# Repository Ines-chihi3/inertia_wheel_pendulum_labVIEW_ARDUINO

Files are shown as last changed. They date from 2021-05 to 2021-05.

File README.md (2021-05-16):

# inertia_wheel_pendulum_labVIEW_ARDUINO

This is a project of designing and controlling the reaction wheel inverted pendulum based entirely on Arduino and labVIEW

https://user-images.githubusercontent.com/83761798/118369695-a4dad180-b5a4-11eb-9695-7480ea213706.mp4

I had the opportunity to work with 3 teammates : slim abid , sonia abbes and eya nagezi on a #LabVIEW project assigned by our professor in the National Institute of Applied Science and Technology in Tunisia.

The project is entitled "inertia wheel pendulum"  and is a well known benchmark in the field of controls . 
it consists of elaborating a system capable of stabilizing the pendulum on the inverted equilibrium point.
This principle is widely used in modern systems such as gymnastic robot .

The project involved  :

* making a mathematical model of the system
* hardware design with solidworks
* Developping a LabVIEW interface for data acquisition and control
* communication design using LINX package for interfacing between arduino and labVEIW
* comparing defferent type of controlor : LQR VS PID 
* Developping a #PID controller and tuning its parameters

This project, was a good opportunity for us to apply the theory we've been learning throughout this academic year , I want to thank my teammates for their support and perseverance .

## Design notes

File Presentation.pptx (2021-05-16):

## LABVIEW project

The inverted pendulum stabilized by a flywheel,
under-actuated non-linear system

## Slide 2

prepared by
Chihi Ines
Abbes Sonia
Abid Slim
Nagazi Eya
IIA4

## Motivation goals: GymnasRobots

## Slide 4

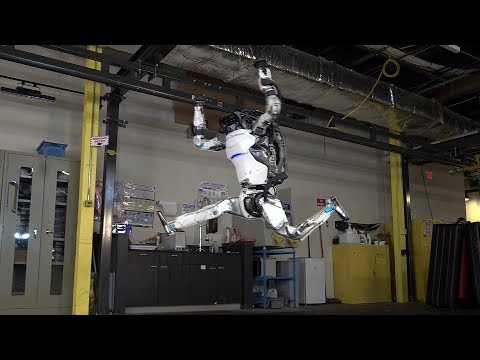
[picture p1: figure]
Atlas uses its whole body -- legs, arms, torso -- to perform a sequence of dynamic maneuvers that form a gymnastic routine. We created the maneuvers using new techniques that streamline the development process. First, an optimization algorithm transforms high-level descriptions of each maneuver in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

## The Benchmark

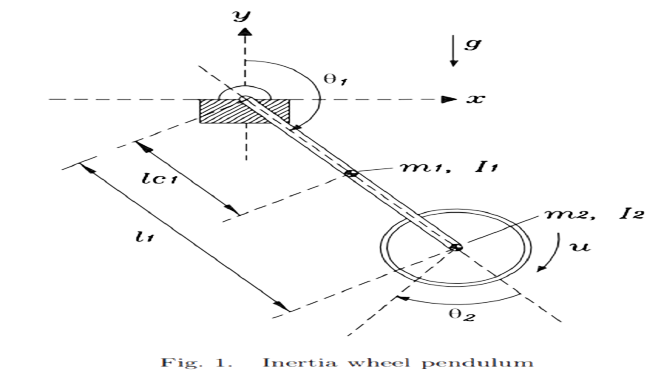
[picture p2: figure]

## Dynamic parameters

Notation | Description | Unit
L1 | Pendulum length | cm
Lc1 | the distance between the gravity center and the rotation axis | cm
m1 | Pendulum mass | Kg
m2 | Wheel mass | Kg
I1 | Pendulum Inertia | Kg.m²
I2 | Wheel Inertia | Kg.m²
g | gravity acceleration | m/s²

## Dynamic Variables

Notation | Description | Unit
θ1 | Pendulum angular position | rad
θ2 | Wheel angular position | rad
(θ1) ̇ | Pendulum angular velocity | rad/s
(θ2) ̇ | Wheel angular velocity | rad/s
(θ1) ̈ | Pendulum angular acceleration | rad/s²
(θ2) ̈ | Wheel angular acceleration | rad/s²
u | Motor torque | Nm

## Modelling hypotheses

Hypothesis 1: The masses of the pendulum and the inertia wheel are considered to be point masses located at their center gravity
Hypothesis 2: the friction mechanical phenomenal will be neglected
Hypothesis 3: The dynamics of the actuator motor associated with the wheel is not taken into account in the modelling of the system

## Theories

Lagrangian field theory:
Q =0 1 .u,
q= (θ1 θ2) T
L=K-V

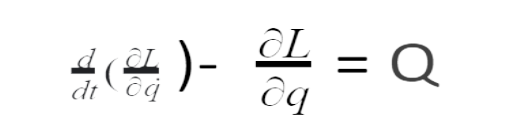
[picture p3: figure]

M=(m11,m12,m21,m22)
m11=m1.lc12+m2l12+I1+I2 m12=m21=m22

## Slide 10

## The dynamic model

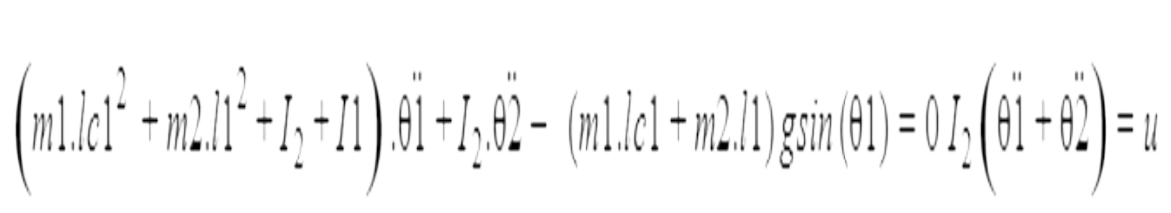
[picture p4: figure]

## Stabilisation

PID:
P:The proportional component depends only on the difference between the set point and the process variable.
I:The integral response will continually increase over time unless the error is zero
D:The derivative component causes the output to decrease if the process variable is increasing rapidly
LQR: Linear quadratic regulator is based on Riccati equations .Minimizing quadratic cost function with properly matched weights is the aim of the controller
target_voltage = a*p_angle + b*p_vel + c*m_vel
- a,b and c are weights
- pendulum angle - p_angle
- pendulum velocity - p_vel
- motor velocity - m_vel

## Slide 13

Model Conception

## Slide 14

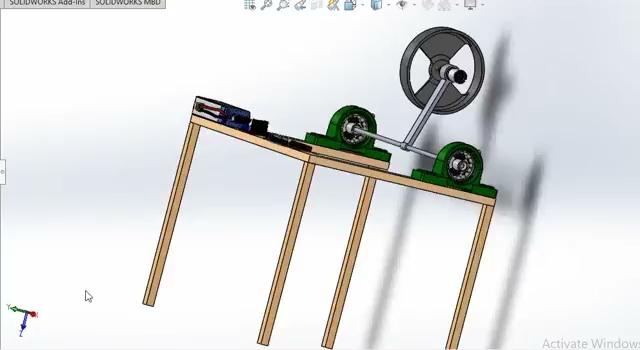
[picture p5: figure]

## Flowchart

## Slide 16

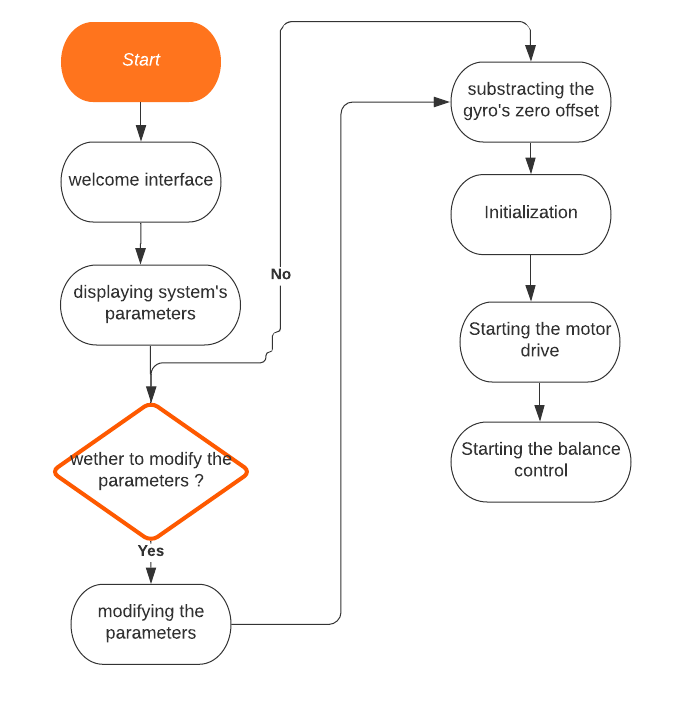
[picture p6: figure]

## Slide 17

Front Panel

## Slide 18

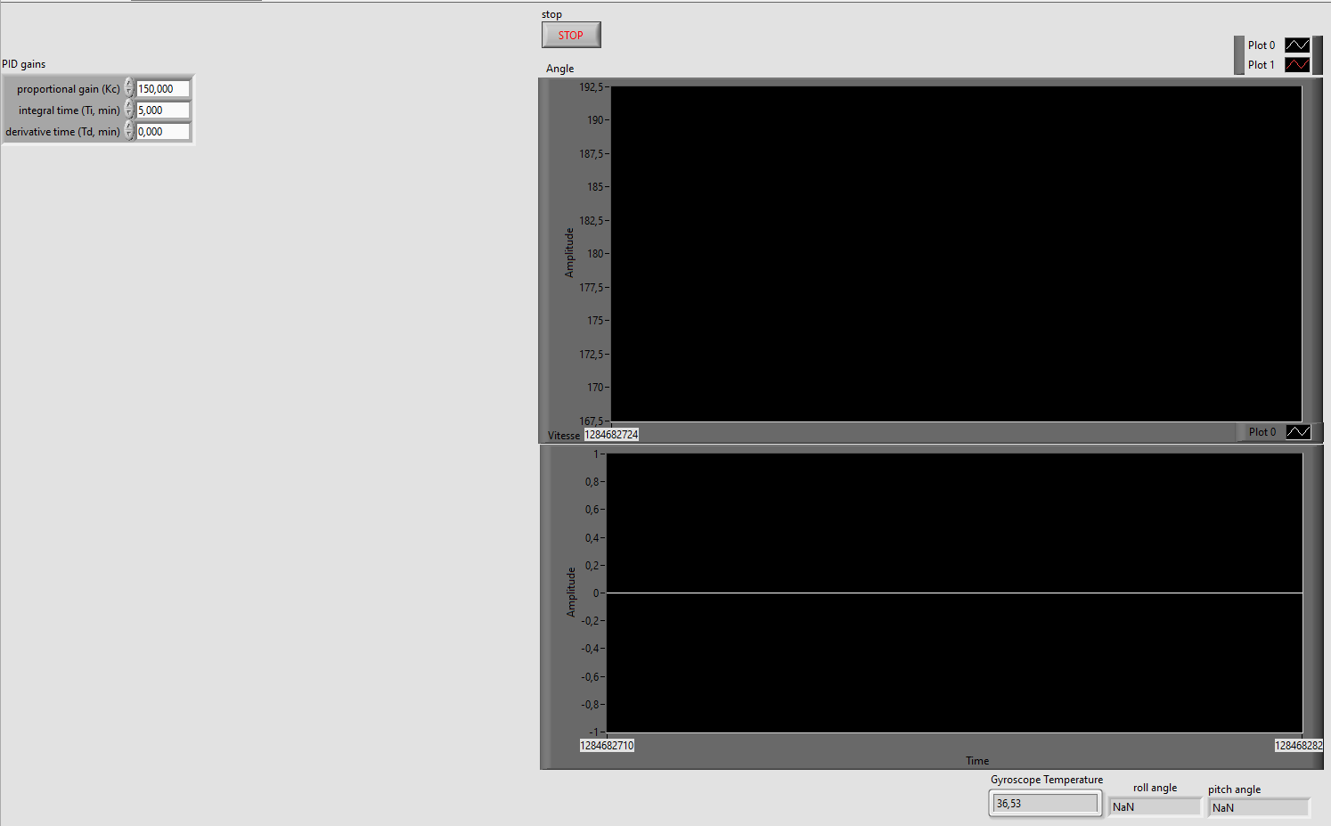
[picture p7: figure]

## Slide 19

Block diagram

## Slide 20

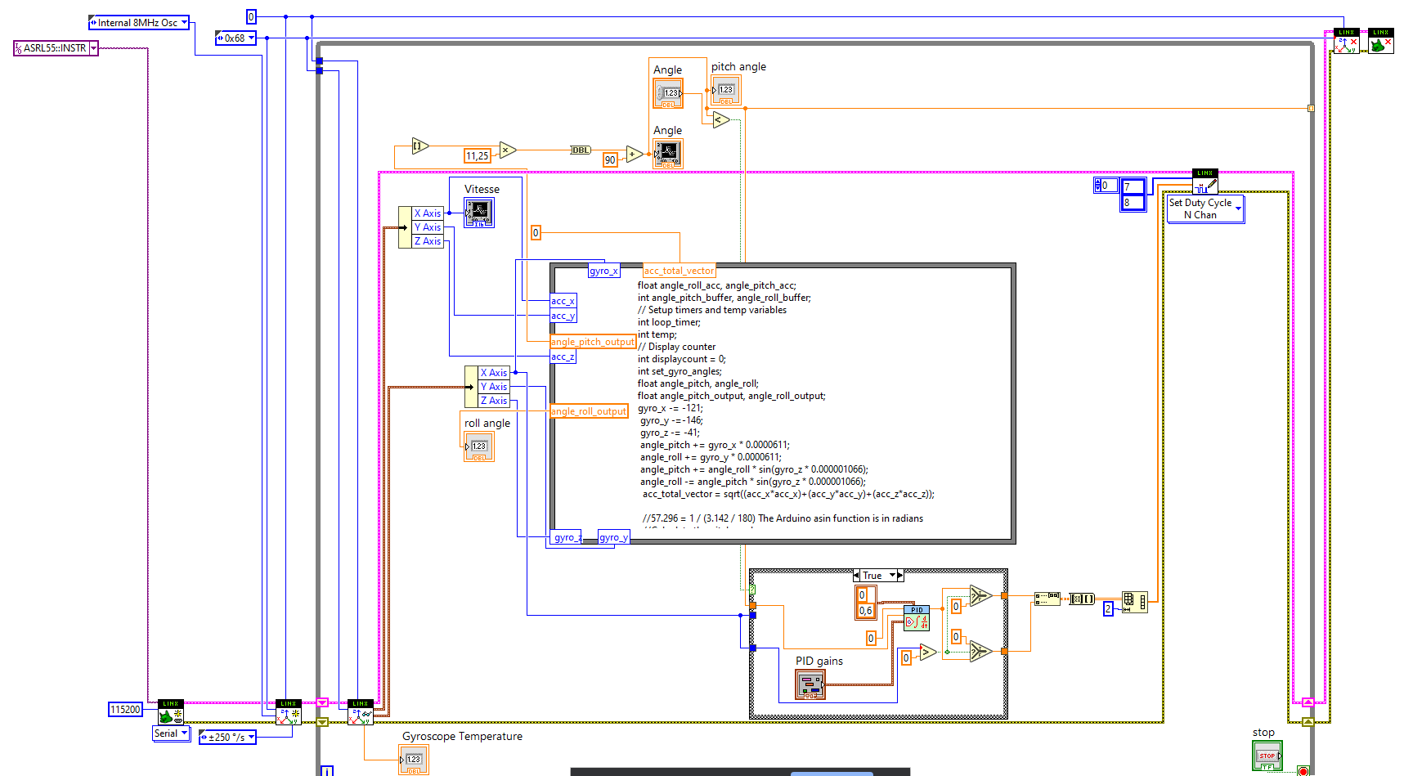
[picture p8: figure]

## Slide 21

Communication technology

Bluetooth: It is an unwired method that use bluetooth module to ensure the communication between the labview and the model
=> No real time results, Problem of latency
Serial: It is a wired method that uses a cable to communicate the software with the model

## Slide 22

Real time test

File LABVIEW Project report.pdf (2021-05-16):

LABVIEW Project report

The inverted pendulum stabilized by a flywheel, a under-actuated non-linear system

prepared by

Chihi Ines

Abbes Sonia

Abid Slim

Nagezi Eya

IIA4

1.3.2 Tab1.Description of dynamic parameters of the inertia wheel inverted pendulum ...... 4

## 1 Introduction

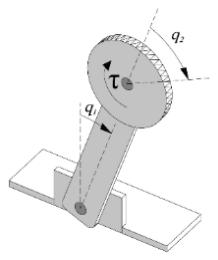
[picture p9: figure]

### 1.1 Scope of the Project:

The Inertia Wheel Pendulum is a benchmark for nonlinear control of under actuated mechanical systems consisting of a physical pendulum with a symmetric disk attached to the tip, which is free to spin about an axis parallel to the axis of rotation of the pendulum. Apart from that, the dynamics of inverted pendulum resembles many real-time systems such as under-actuated robot manipulators, gymnast robots, undersea vehicles, aircrafts, some mobile robots and humanoid robots. In control theory, inertia wheel pendulum is being treated as one of the most attractive systems to test emerging Control strategies due to its distinct features of instability, nonlinearity and under actuation.

### 1.2 Motivation goals:

From the last few decades, inertia wheel pendulums have become a benchmark problem In dynamics and control theory. Due to their inherent nature of nonlinearity, Instability and under actuation. The dynamics of inertia wheel pendulum systems resemble many real-world systems such as Atlas Humanoid robot, it is primarily developed by Boston Dynamics, with funding and oversight from the Defence Advanced search Projects Agency (DARPA).This 1.88 m and 82 kg model is designed for various researches and rescue tasks, it can carry packages, open doors but also stand up when it is pushed or unbalanced.it is designed to push the limits of whole-body mobility and to demonstrate human-level agility.

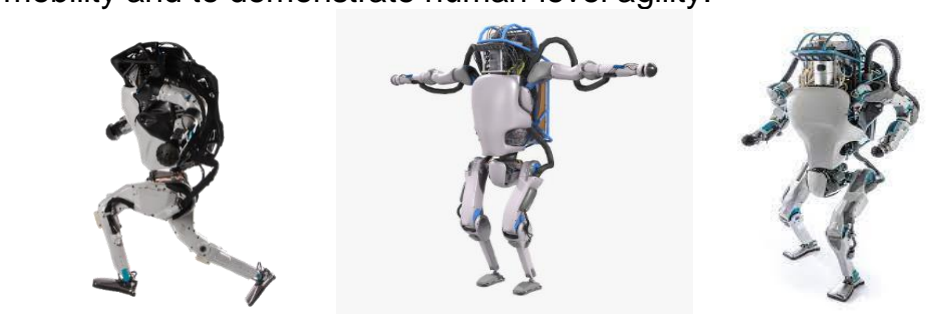
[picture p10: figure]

### 1.3 presentation of the benchmark:

1.3.1 Inertia wheel pendulum figure The Reaction Wheel Pendulum is shown schematically in Fig. 1. It is a physical pendulum with a symmetric disk attached to the end which is free to spin about an axis parallel to the axis of rotation of the pendulum. The disk is actuated by a DC-motor and the coupling torque generated by the angular acceleration of the disk can be used to actively control the system.

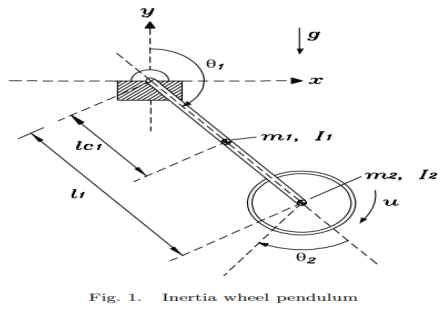
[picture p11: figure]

1.3.2 | Tab1.Description of dynamic parameters of the inertia wheel inverted pendulum
Notation | Description | value
l1 | Length of the pendulum | …….m
lc1 | Distance at the center of mass lc1 m of the pendulum | | m
m1 | Mass of the pendulum | …..kg
m2 | Mass of the disc | ….kg
I1 | Moment of inertia of the pendulum | ….kg.m2
I2 | Moment of inertia of the wheel | ….kg.m2
g | Gravity acceleration | | m/s2
1.3.3 | Tab2.Description of dynamic variables of the inertia wheel inverted pendulum

## 2 Theoretical study:

### 2.1 modelling hypothèses

✓ | Hypothesis 1: The masses of the pendulum and the inertia wheel are
| considered to be point masses located at their centres of gravity.
✓ | Hypothesis 2: The study of the dynamics of the inertia wheel pendulum is
| carried out by neglecting the friction mechanical phenomenal.
✓ | Hypothesis 3: The dynamics of the actuator motor associated with the wheel
| is not taken into account in the modelling of the system

### 2.2 Dynamic model of the system using Lagrange model :

The nonlinear model of the inertia wheel pendulum can be also obtained using Lagrange equation. This method consist of the calculation of the Lagrengian. The Lagrange formalism is based on the equation:

| d
| dt ( ∂L
| ∂q̇ )- ∂L ∂q= Q
Where Q =( | 0
| 1 ) . u, q= (θ1 θ2) T, the Lagrengian is given by L=K-V where K is the kinetic

energy and is the potential energy. For the nonlinear systems these energies can be written as the following:

Variables | Description | Unit
θ1 | Pendulum angular position | rad
θ1̇ | Pendulum angular velocity | Rad/s
θ1̈ | Pendulum angular acceleration | Rad/s²
θ2 | Wheel angular position | rad
θ2̇ | Wheel angular velocity | Rad/s
θ2̈ | Wheel angular acceleration | Rad/s²
u | Motor torque | Nm

{
K =

1
2

q̇T . M. q̇
v = βcos (θ1)

Where M is the system matrix given by M=( m11 m12 m21 m22), the different

coefficients are:
{
m11 = m1. lc1

2 + m2l1

2 + I1 + I2
m12 = m21 = m22 | So we can tell the the expression of the kinetic

energy is

The β coefficent in the potentiel enery is given by β= (m1.lc1+m2.l1).g, so the potential energy is:

In result the Lagrengian expression is:

We begin by calculating the first term which is ∂L ∂q=(
∂L
∂θ1
∂L
∂θ2

)=(
(m1. lc1 + m2.l1)gsin(θ1)
0

)

Then we calculated the second term which is

∂L
∂q̇

=(
∂L
∂θ1̇
∂L
∂θ2̇

)=(
(m1. lc1

2 + m2. l1

2 + I1

). θ1̇ + I2(θ1̇ + θ2)

̇
I2(θ1̇ + θ2)

̇

) the last term that need to be

calculated now is

d
dt

(

∂L
∂q̇

) = (
d
dt (

∂L
∂θ1̇

)

d
dt (

∂L
∂θ2̇

)

)=(
(m1.lc1

2 + m2. l1

2 + I2 + I1). θ1̈ + I2. θ2̈ I2(θ1̈ + θ2̈ )

)

So the Lagrengian equation can be written as:
(
(m1.lc1

2 + m2. l1

2 + I2 + I1). θ1̈ + I2. θ2̈ − (m1. lc1 + m2. l1)gsin(θ1) I2(θ1̈ + θ2̈ )

)=(
0
1

) . u

Finally, the dynamics that characterized the inertia wheel pendulum is
{
(m1. lc1

2 + m2. l1

2 + I2 + I1). θ1̈ + I2. θ2̈ − (m1. lc1 + m2.l1)gsin(θ1) = 0 I2(θ1̈ + θ2̈) = u

### 2.3 PID theory:

For the control of the stability, we used the Proportional-Integral-Derivative (PID) control which is the most common control algorithm used in industry and has been universally accepted in industrial control. The popularity of PID controllers can be attributed partly to their robust performance in a wide range of operating conditions and partly to their functional simplicity, which allows engineers to operate them in a simple, straightforward manner.
As the name suggests, PID algorithm consists of three basic coefficients; proportional, integral and derivative which are varied to get optimal response. Closed loop systems, the

K=¹
2

(m1.lc1²+I1)².θ1̇ 2 +

1
2

.m2.l1². .θ2̇ 2 +

1
2

(θ1̇ +θ2̇ )
2

V= (m1.lc1+m2.l1).g. cos (θ1)

L=¹
2

(m1.lc1²+I1)².θ1̇ 2 +

1
2

.m2.l1². .θ2̇ 2 +

1
2

(θ1̇ +θ2̇ )
2 - (m1.lc1+m2.l1).g. cos (θ1)

theory of classical PID and the effects of tuning a closed loop control system are discussed in this paper. The PID toolset in Labview and the ease of use of these VIs is also discussed.

2.3.1 Proportional Response

The proportional component depends only on the difference between the set point and the process variable. This difference is referred to as the Error term. The proportional
gain (Kc) determines the ratio of output response to the error signal. In general, increasing the proportional gain will increase the speed of the control system response. However, if the proportional gain is too large, the process variable will begin to oscillate. If Kc is increased further, the oscillations will become larger and the system will become unstable and may even oscillate out of control.
2.3.2 Integral Response

The integral component sums the error term over time. The result is that even a small error term will cause the integral component to increase slowly. The integral response will continually increase over time unless the error is zero, so the effect is to drive the Steady-State error to zero. Steady-State error is the final difference between the process variable and set point. A phenomenon called integral windup results when integral action saturates a controller without the controller driving the error signal toward zero.
2.3.3 Derivative Response

The derivative component causes the output to decrease if the process variable is increasing rapidly. The derivative response is proportional to the rate of change of the process variable. Increasing the derivative time (Td) parameter will cause the control system to react more strongly to changes in the error term and will increase the speed of the overall control system response. Most practical control systems use very small derivative time (Td), because the Derivative Response is highly sensitive to noise in the process variable signal. If the sensor feedback signal is noisy or if the control loop rate is too slow, the derivative response can make the control system unstable.

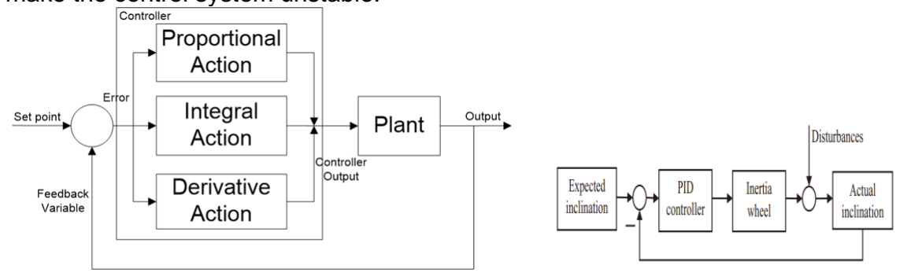
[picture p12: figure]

Fig.2 Block diagram of a basic PID control algorithm. | Fig3. Closed loop using a PID

## 3 Experimental study:

### 3.1 Hardware Conception:

3.1.1 Mechanical Hardware
It is composed of a support which supports the pendulum through a passive link (pivot). The body of the pendulum supports a flywheel operated by a direct current motor. The rotation of

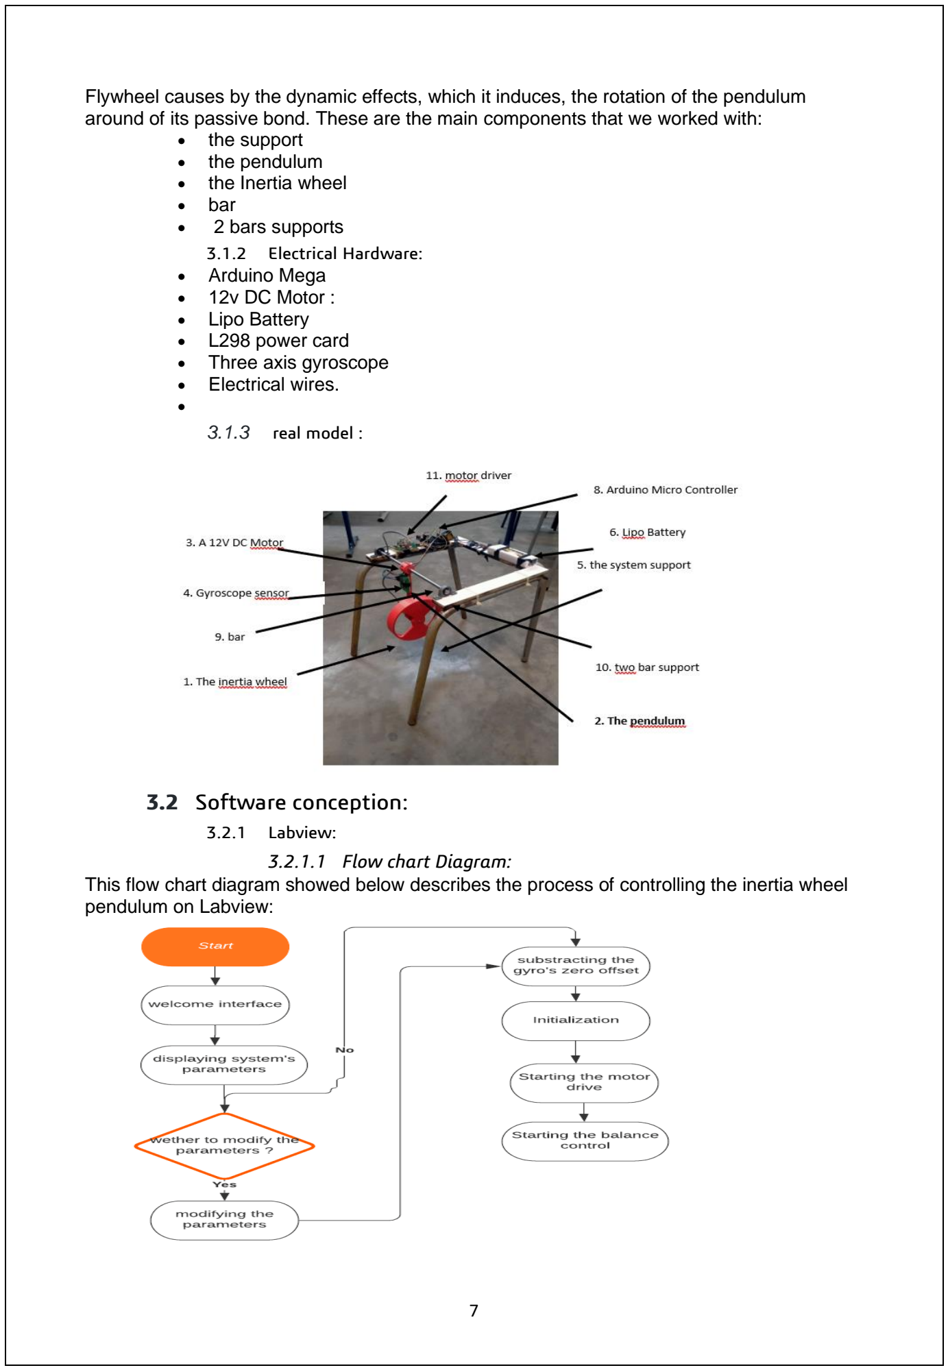
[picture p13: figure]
• the support • the pendulum • the Inertia wheel • bar • 2 bars supports; Electrical Hardware:; • Arduino Mega • 12v DC Motor : • Lipo Battery • L298 power card • Three axis gyroscope • Electrical wires.; real model :; 3.2 Software conception:; Labview:; 3.2.1.1 Flow chart Diagram:; pendulum on Labview:

Flywheel causes by the dynamic effects, which it induces, the rotation of the pendulum around of its passive bond. These are the main components that we worked with:

This flow chart diagram showed below describes the process of controlling the inertia wheel

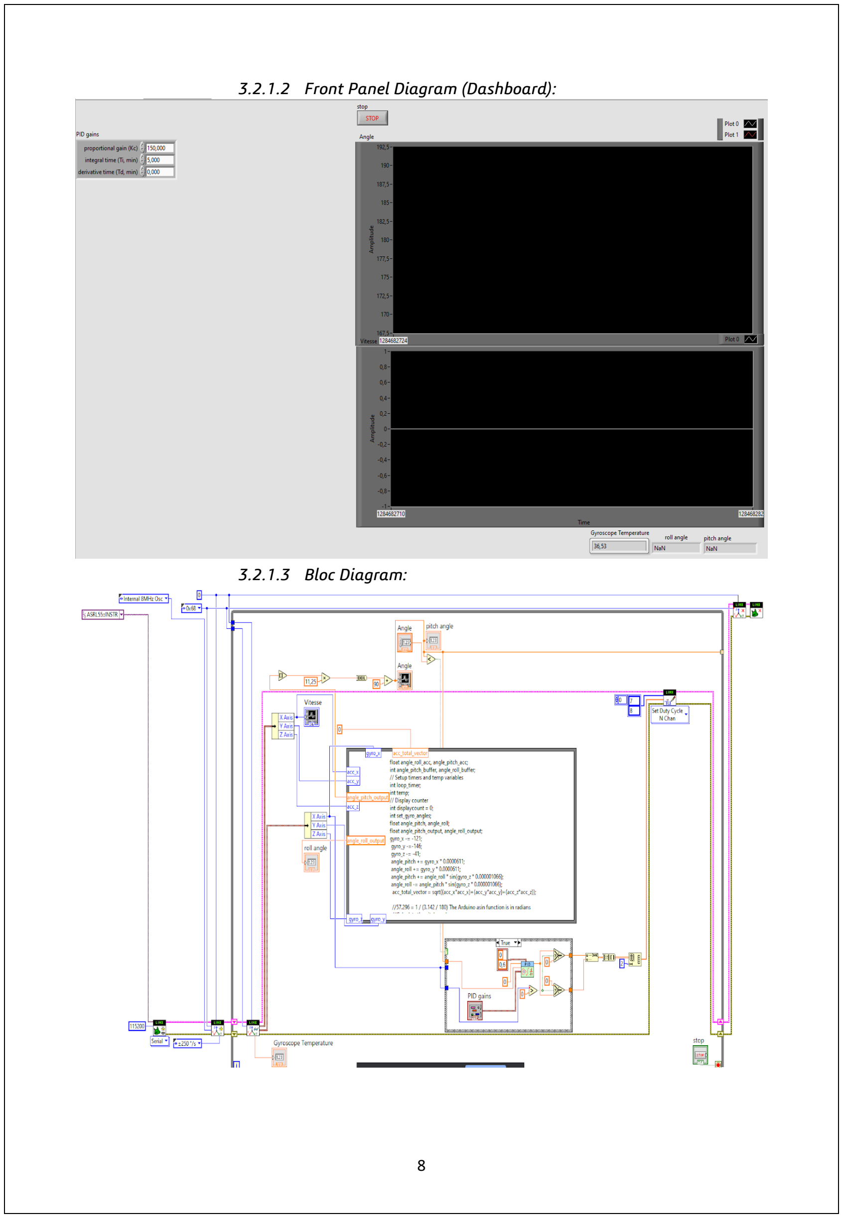
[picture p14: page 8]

3.2.1.2 Front Panel Diagram (Dashboard):

3.2.1.3 Bloc Diagram:

3.2.2 Solidworks:
The conception of our model was realized on the Solidworks Software. The screen capture below presents most of the materiel that we’ve used in this project:

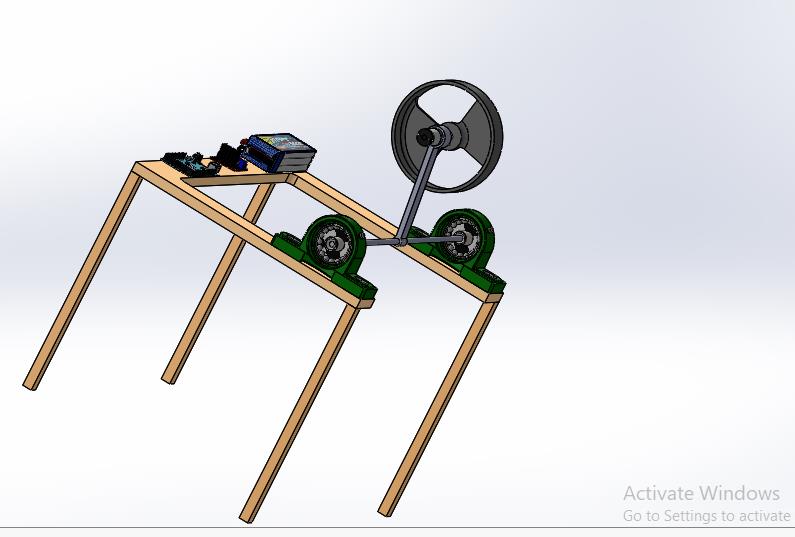
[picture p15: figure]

### 3.3 communication technology

Bluetooth: It is an unwired method that use bluetooth module to ensure the communication between the labview and the model

=> No real time results, Problem of latency

Serial: It is a wired method that uses a cable to communicate the software with the model

## 4 Results:

This chart presents the variation of the pitch angle, it takes values between 0 and 180 degrees where 180 represents the stable equilibrium point (uppoint) and the 0 represents the instable equilibrium point (downpoint)

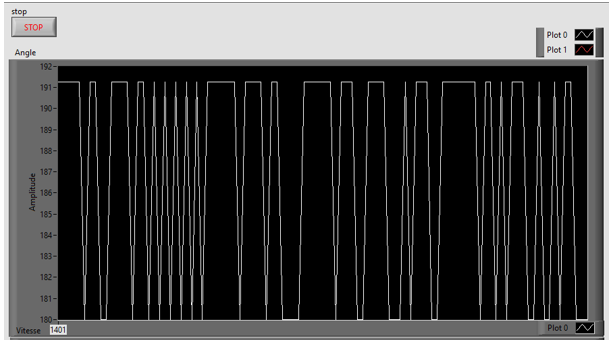
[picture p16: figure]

Chart1: pitch angle variation (the angle with respect to the x axis)

This chart represents the acceleration with respect to x axis, it takes positive values if the wheel turns on the clockwise and negative values it turns on indirect clockwise.

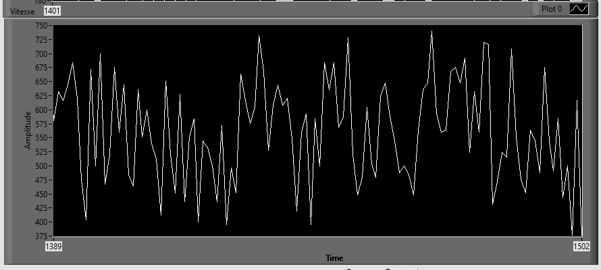
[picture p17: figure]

Chart 2: the acceleration of the wheel with respect the x axis

these three indicators represent respectively the gyroscope intern temperature, the roll angle and the pitch angle.

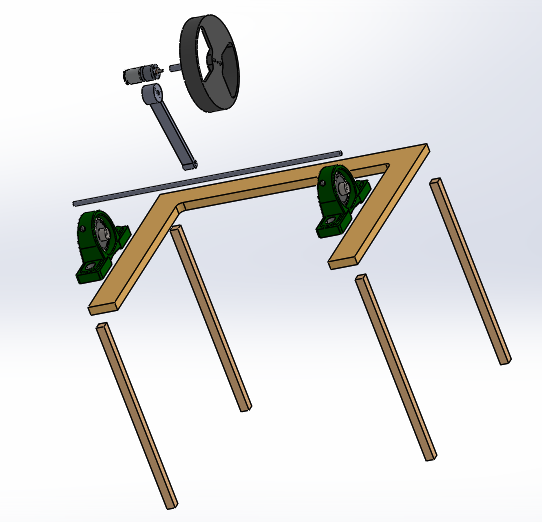
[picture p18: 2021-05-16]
SolidWorks design/vue eclatée.PNG

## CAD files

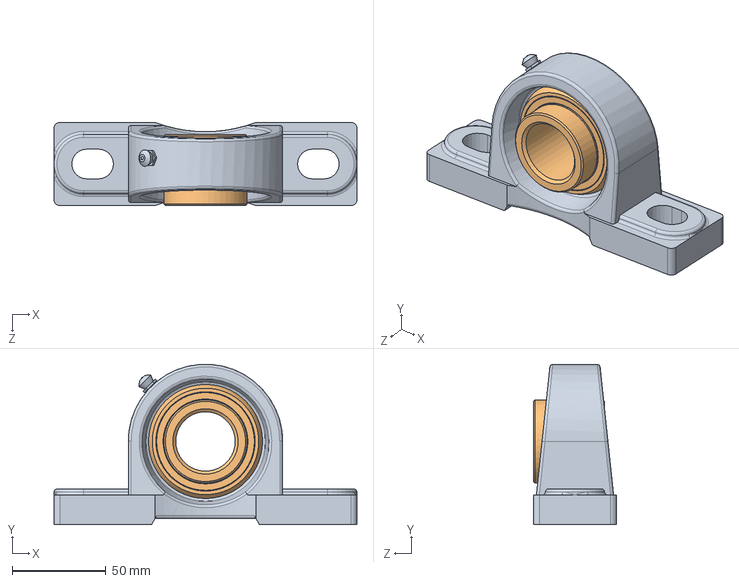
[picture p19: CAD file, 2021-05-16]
SolidWorks design/PEDESTAL BEARING.SLDASM
161.9 x 85.6 x 44.5 mm
BLOCK
BEARING

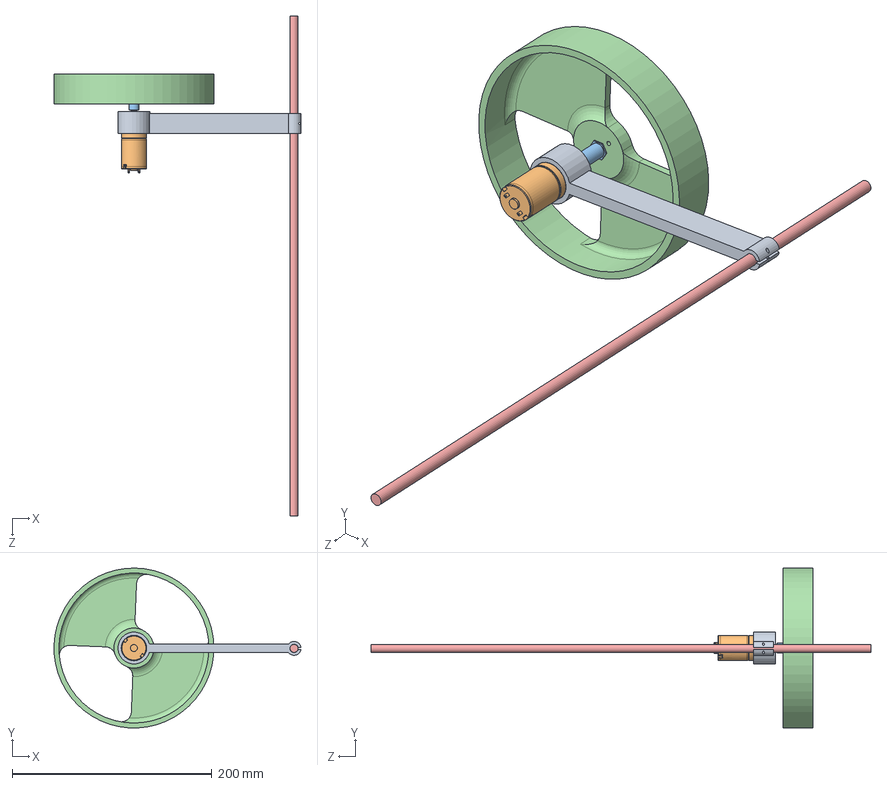
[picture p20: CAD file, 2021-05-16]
SolidWorks design/ass final.SLDASM
247.0 x 159.9 x 500.0 mm
bras petit moteur final
JGA25-370 12V Planetary Geared Motor
accouplement
reaction_wheel final
rail 8mm petit robot

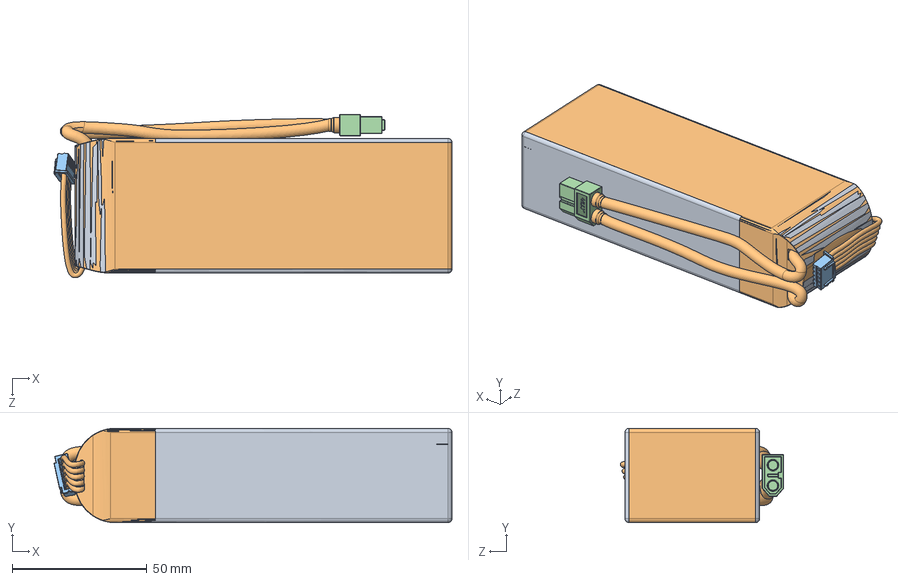
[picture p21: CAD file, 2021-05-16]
SolidWorks design/Bateria Lipo.SLDASM
147.7 x 35.0 x 60.7 mm
Funda de la bateria
Nucleo de la bateria
Conector
Conector XT60

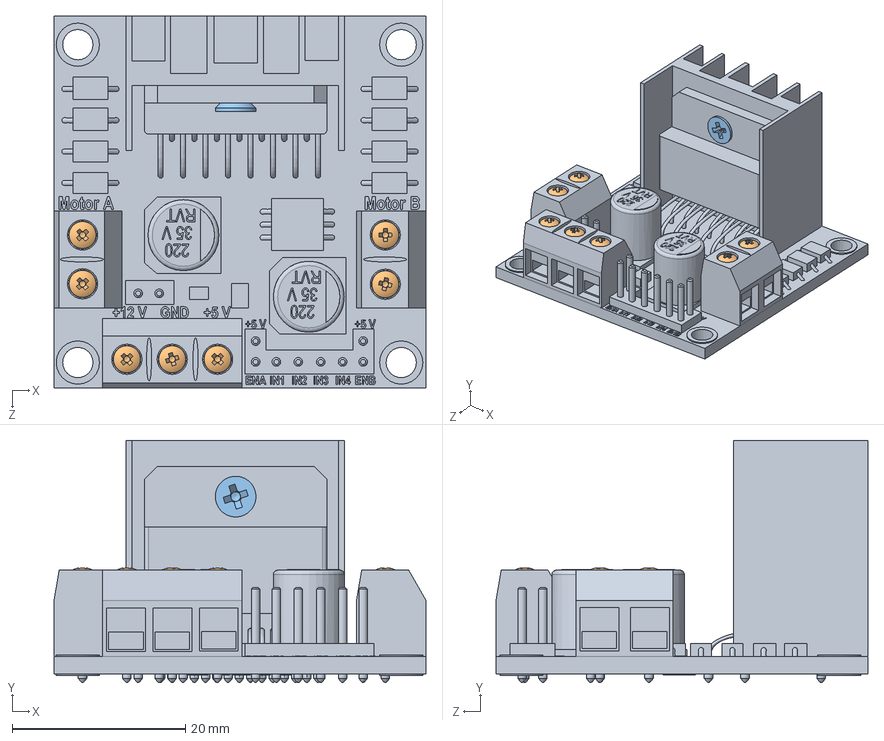
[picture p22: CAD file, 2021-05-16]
SolidWorks design/L298N Stepper Motor Driver Assembly.SLDASM
43.0 x 28.0 x 43.0 mm
L298N Stepper Motor Driver (Red)-Part File
pan head cross recess screw_iso_ISO 7045 - M1.6 x 4 - Z - 4N x 7
countersunk flat head cross recess screw_iso_ISO 7046-1 - M2.5 x 3 - Z - 3N

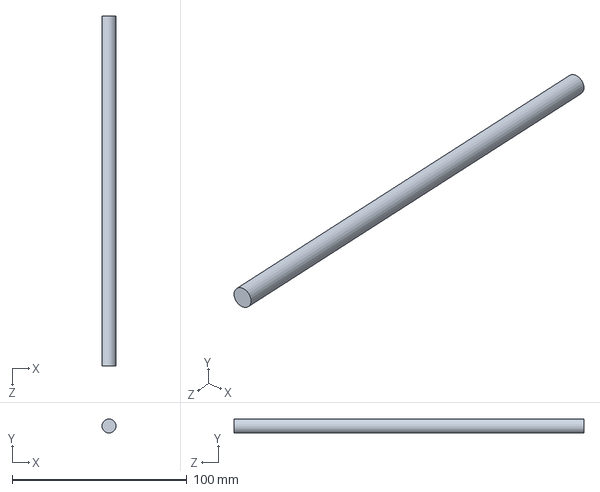
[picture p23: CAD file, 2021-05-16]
SolidWorks design/rail 8mm petit robot.SLDPRT
8.00 x 8.00 x 200.0 mm

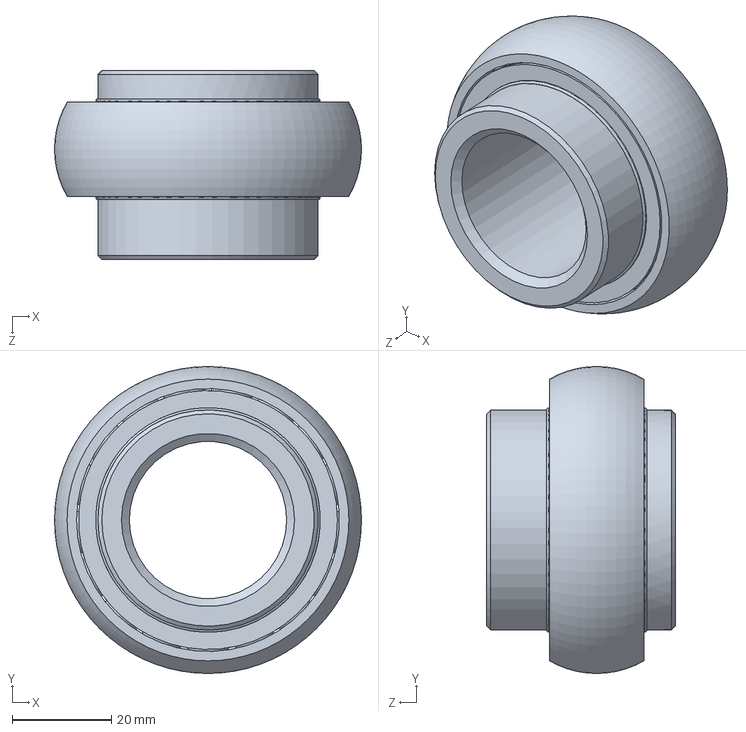
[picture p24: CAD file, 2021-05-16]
SolidWorks design/BEARING.SLDPRT
62.0 x 62.0 x 38.1 mm

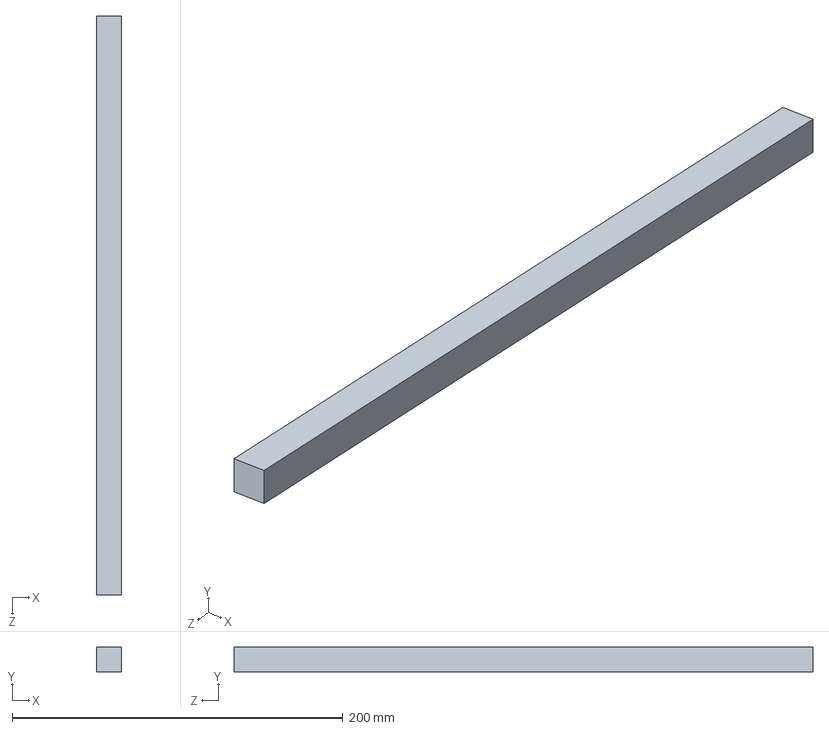
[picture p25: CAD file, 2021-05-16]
SolidWorks design/pied châssis.SLDPRT
15.0 x 15.0 x 350.0 mm

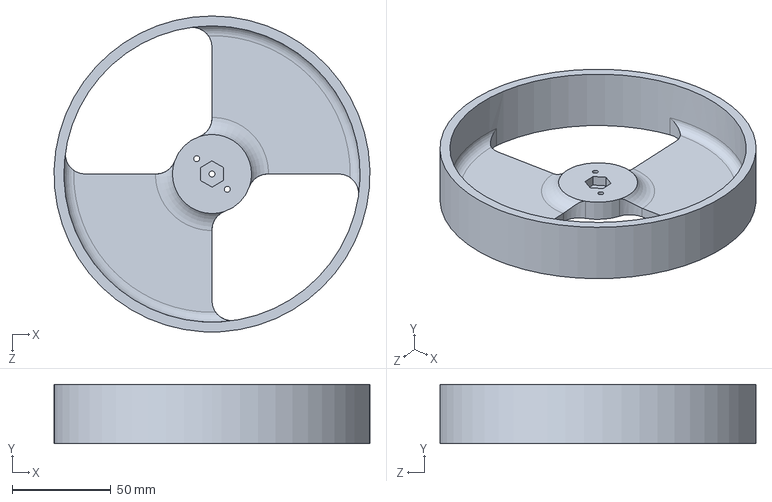
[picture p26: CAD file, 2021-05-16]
SolidWorks design/reaction_wheel final.SLDPRT
159.9 x 30.0 x 160.0 mm

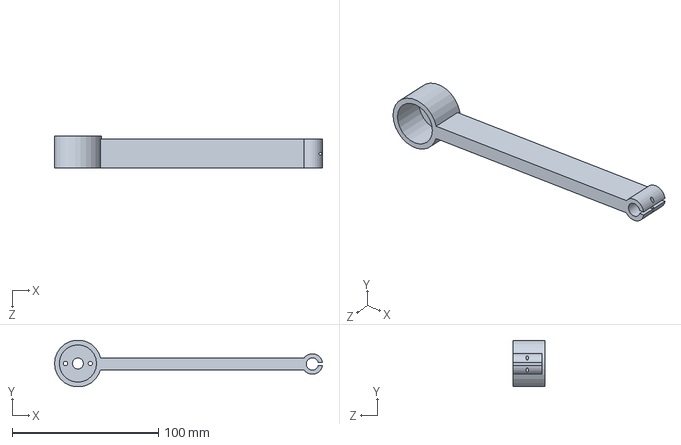
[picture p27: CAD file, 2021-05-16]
SolidWorks design/bras petit moteur final.SLDPRT
183.1 x 31.8 x 22.0 mm

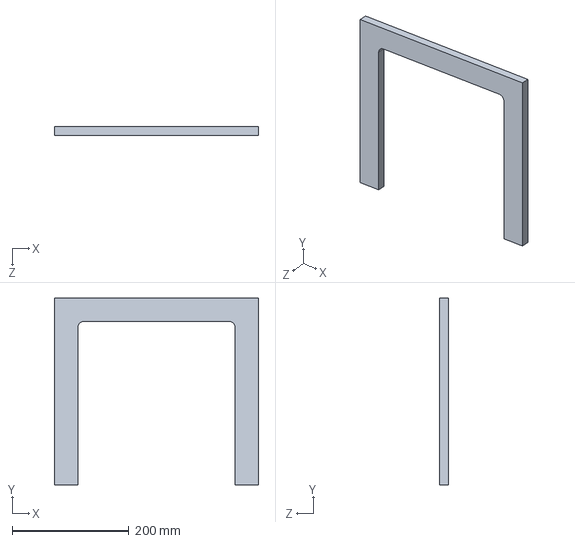
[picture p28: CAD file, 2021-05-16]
SolidWorks design/chassit.SLDPRT
350.0 x 320.0 x 15.0 mm

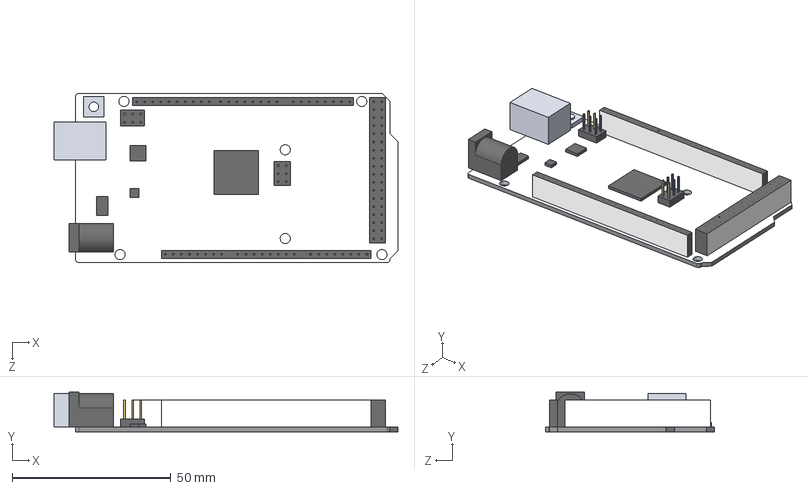
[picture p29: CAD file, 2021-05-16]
SolidWorks design/arduinoMegaSimplified.STEP
108.3 x 12.5 x 53.3 mm

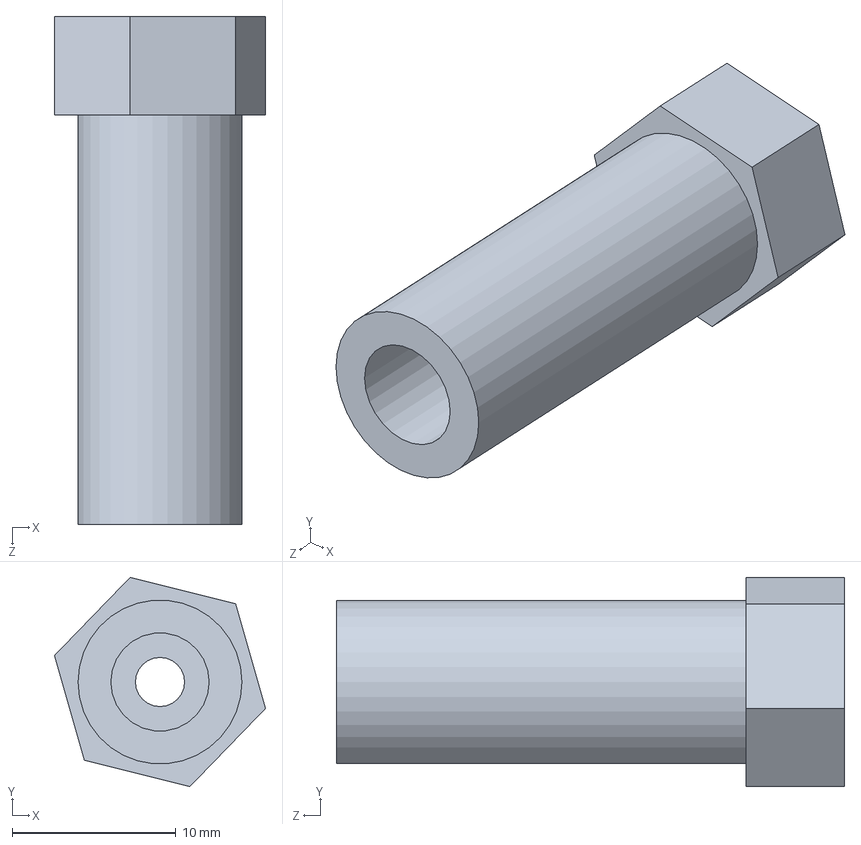
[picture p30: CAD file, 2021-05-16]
SolidWorks design/accouplement.SLDPRT
12.9 x 12.8 x 31.0 mm

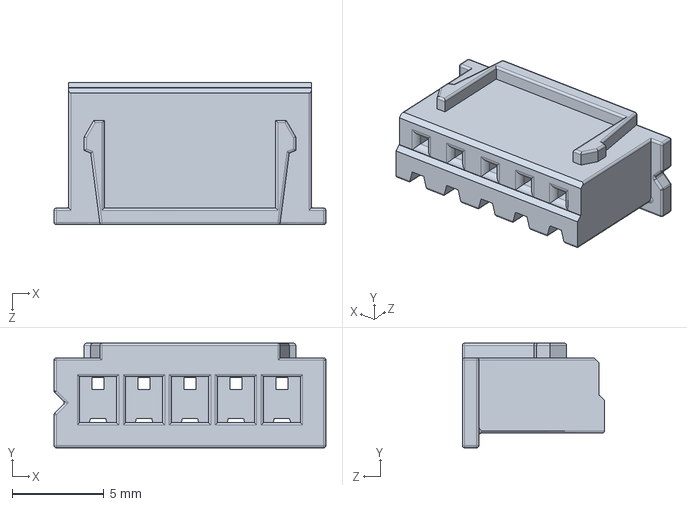
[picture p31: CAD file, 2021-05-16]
SolidWorks design/Conector.SLDPRT
14.8 x 5.70 x 7.75 mm

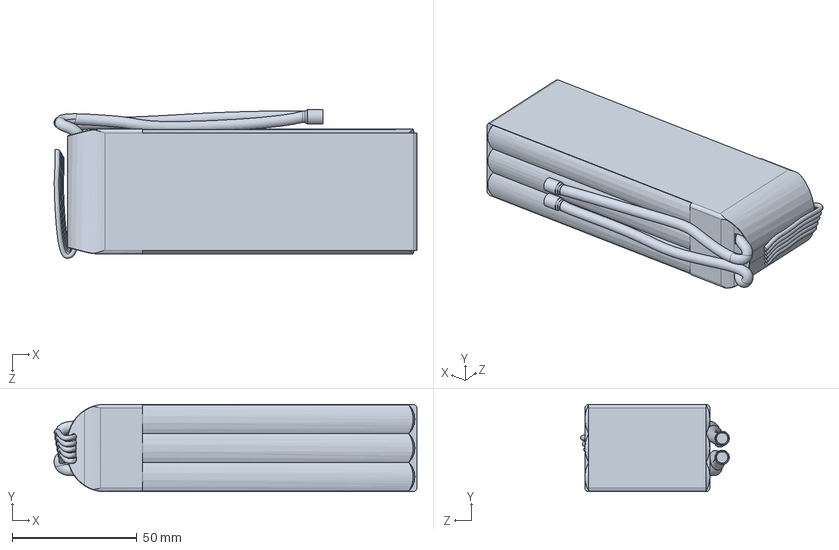
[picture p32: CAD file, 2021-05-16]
SolidWorks design/Nucleo de la bateria.SLDPRT
145.4 x 35.0 x 59.5 mm

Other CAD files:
SolidWorks design/L298N Stepper Motor Driver (Red)-Part File_1.sldprt
SolidWorks design/BLOCK.SLDPRT
SolidWorks design/Funda de la bateria.SLDPRT
SolidWorks design/JGA25-372 24V Motor.STEP
SolidWorks design/Conector XT60.SLDPRT
SolidWorks design/Cytron Motor.STEP
SolidWorks design/JGA25-370 12V Planetary Geared Motor.SLDPRT
SolidWorks design/JGA25-372 24V Motor.IGS
SolidWorks design/JGA25-372 24V Motor.x_t
SolidWorks design/countersunk flat head cross recess screw_iso_ISO 7046-1 - M2.5 x 3 - Z - 3N.sldprt
SolidWorks design/countersunk flat head cross recess screw_iso_ISO 7046-1 - M2.5 x 3 - Z - 3N_1.sldprt
SolidWorks design/pan head cross recess screw_iso_ISO 7045 - M1.6 x 4 - Z - 4N.sldprt
SolidWorks design/pan head cross recess screw_iso_ISO 7045 - M1.6 x 4 - Z - 4N_1.sldprt
